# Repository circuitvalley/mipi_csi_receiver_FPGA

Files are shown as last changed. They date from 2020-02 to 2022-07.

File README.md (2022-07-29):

# MIPI CSI-2 Receiver on FPGA , USB 3.0 UVC 2Gbps Video Stream Over Cypress FX3 , Legacy!!

This Repo contains hardware, Verilog source and USB3.0 USB video device class (UVC) Controller C source for generic FPGA CSI receiver. No FPGA hardware specific components has been used so can be easily ported to any low cost FPGA. 

Supports Frame Rate from 15 to 1000 FPS , Resolution From 640x80 to Full 8M 3280x2464.<br>
Max data rate ~2Gbps at 1080p 60FPS. <br>
Full control of Frame rate and Resolution over UVC control. Manual Exposure and manual Brightness control for now. Manual exposure is mapped to UVC saturation Control. Test Pattern can also be enabled with mapped gamma control. 

Test Has been done at</br>
3280x2464 15FPS</br>
1920x1080 60FPS</br>
1920x1080 30FPS</br>
1280x720  120FPS</br>
1280x720  60FPS</br>
1280x720  30FPS</br>
640x480   200FPS</br>
640x480   30FPS</br>
640x128   682FPS</br>
640x80    1000FPS</br>

### This is Now Legacy Version! New version available.
I have published an improved version of FPGA ISP implimention, New version support versious Image format with variable Pipleline width and Higher speed also decoulped Output clock to achive higer throughput , here you can find source of new version here. 
https://github.com/circuitvalley/USB_C_Industrial_Camera_FPGA_USB3

MIPI CSI-2 Receiver on Lattice FPGA (c) by Gaurav Singh www.CircuitValley.com
MIPI CSI-2 Receiver on Lattice FPGA is licensed under a
Creative Commons Attribution 3.0 Unported License.
You should have received a copy of the license along with this
work.  If not, see <http://creativecommons.org/licenses/by/3.0/>.

Shield: [][cc-by]

This work is licensed under a [Creative Commons Attribution 4.0 International
License][cc-by].

[][cc-by]

[cc-by]: http://creativecommons.org/licenses/by/4.0/
[cc-by-image]: https://i.creativecommons.org/l/by/4.0/88x31.png
[cc-by-shield]: https://img.shields.io/badge/License-CC%20BY%204.0-lightgrey.svg

## Camera module 

https://www.circuitvalley.com/2020/02/diy-imx219-4-lane-mipi-breakout-board-raspberry-pi-camera-fpga-4-lane-mipi-csi.html

https://www.circuitvalley.com/2020/02/imx219-camera-mipi-csi-receiver-fpga-lattice-raspberry-pi-camera.html

## Project Video
<a href="https://www.youtube.com/watch?v=HxytsTGWODs">
IMX219
</a>

## Sensor Board Video 
<a href="https://www.youtube.com/watch?v=GFmE3KYa5zs">
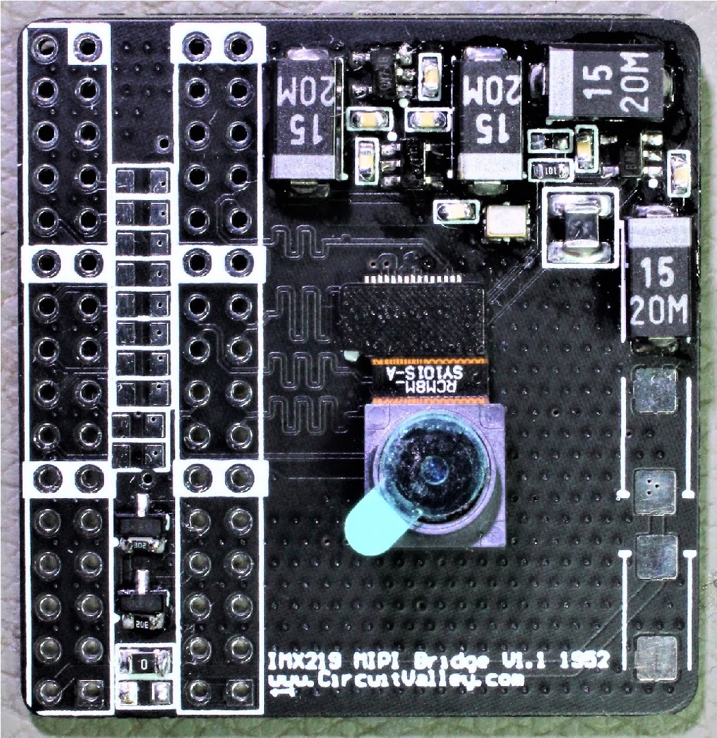
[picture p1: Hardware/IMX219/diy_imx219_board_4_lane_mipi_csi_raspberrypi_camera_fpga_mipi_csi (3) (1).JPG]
IMX219

</a>

## Sensor Image Qaulity Video 

<a href="https://www.youtube.com/watch?v=uRaHXo-Zu90">
IMX219
</a>

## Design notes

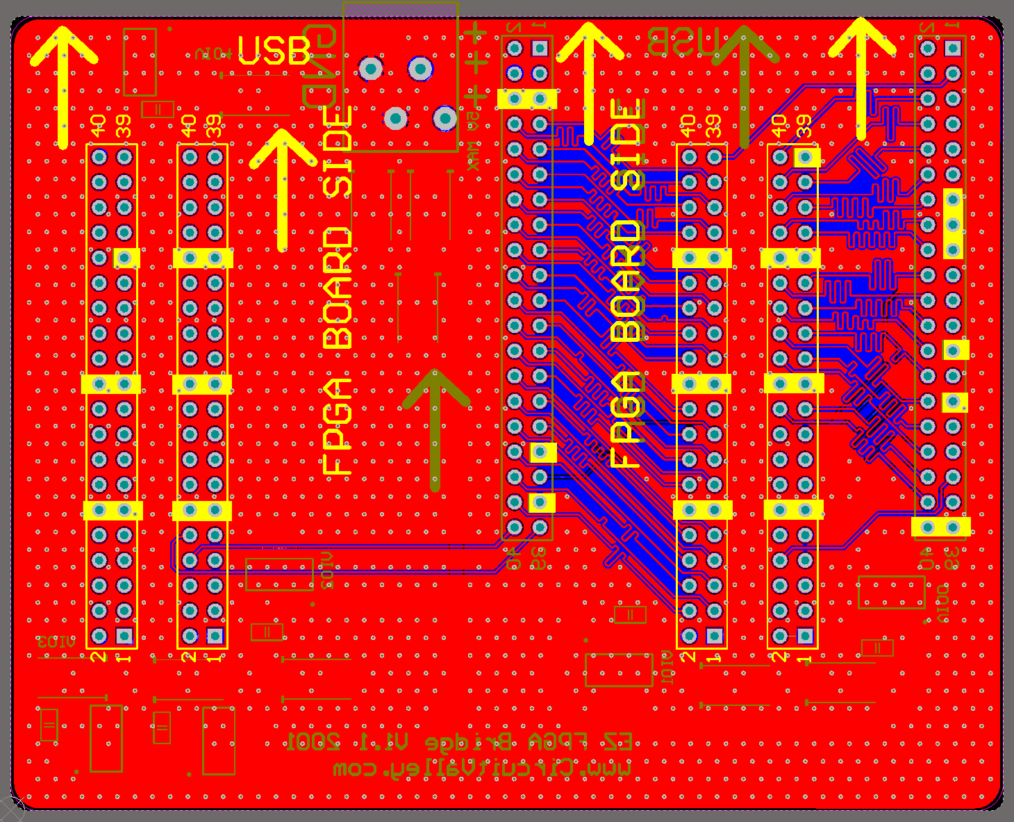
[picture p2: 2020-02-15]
Hardware/Lattice MachXO3 USB3 FX3 Interface Board/Cypress FX3 Lattice MachXO3 FPGA.png

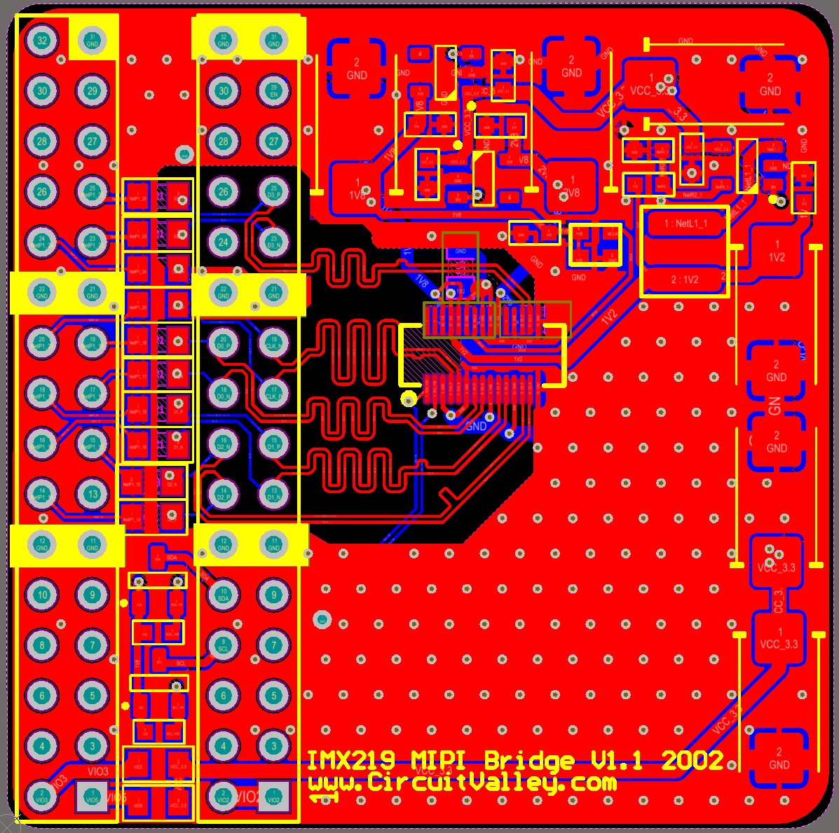
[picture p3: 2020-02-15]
Hardware/IMX219/diy_imx219_board_4_lane_mipi_csi_raspberrypi_camera_fpga_mipi_csi (8).JPG

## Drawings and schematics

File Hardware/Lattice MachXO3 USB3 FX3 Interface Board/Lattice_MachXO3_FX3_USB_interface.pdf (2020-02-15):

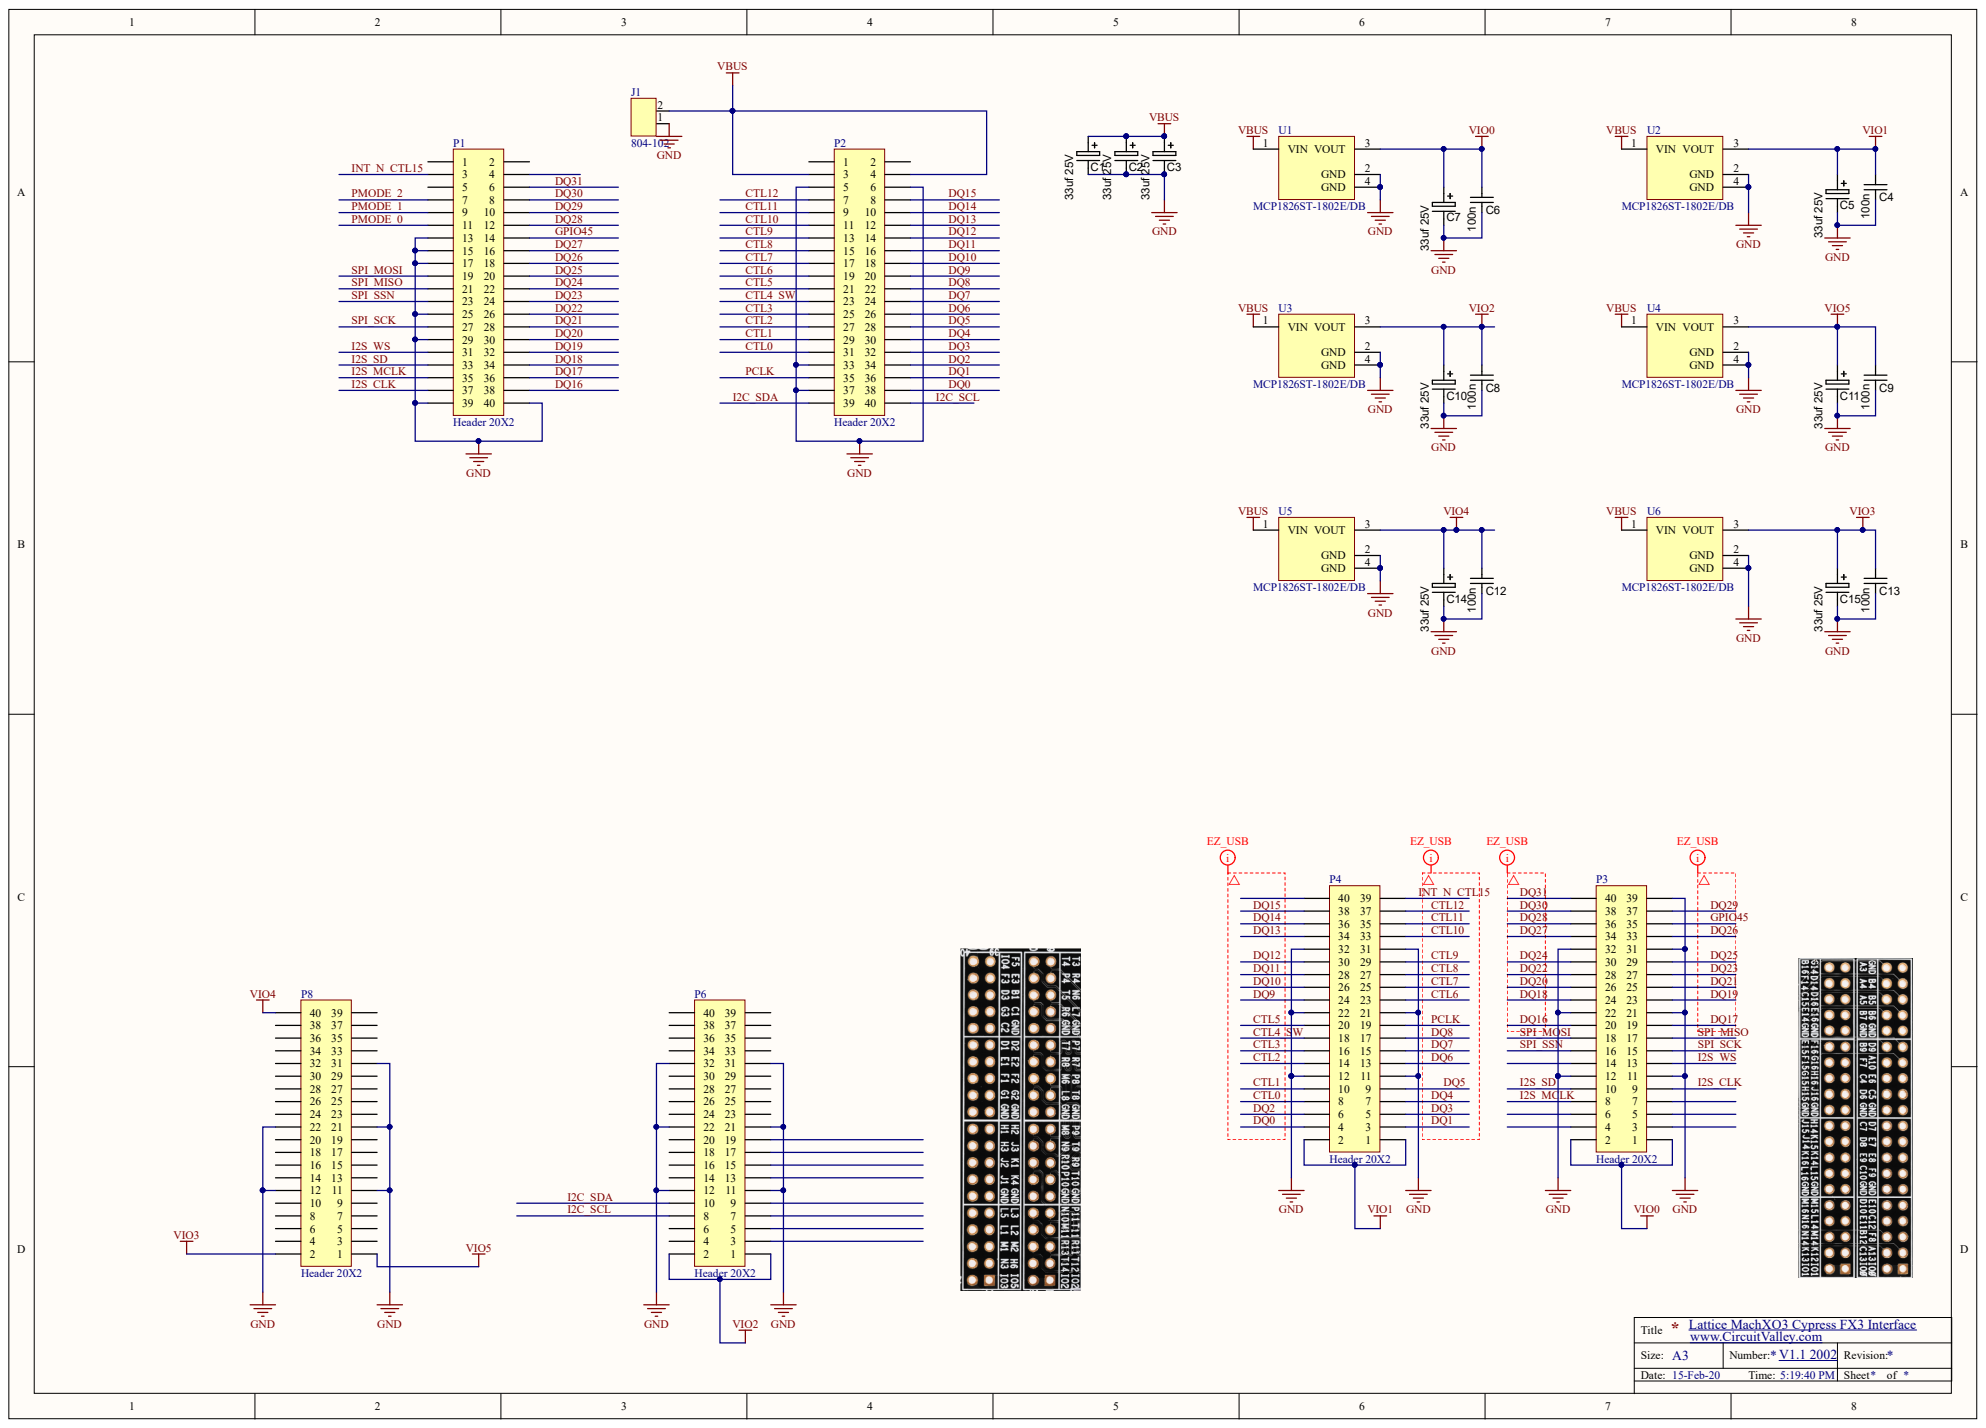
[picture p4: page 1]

Lattice MachXO3 Cypress FX3 Interface www.CircuitValley.com
Title

Size: A3 | Number: * V1.1 2002 | Revision: *

Date: 15-Feb-20 Time: 5:19:40 PM | | Sheet * of *

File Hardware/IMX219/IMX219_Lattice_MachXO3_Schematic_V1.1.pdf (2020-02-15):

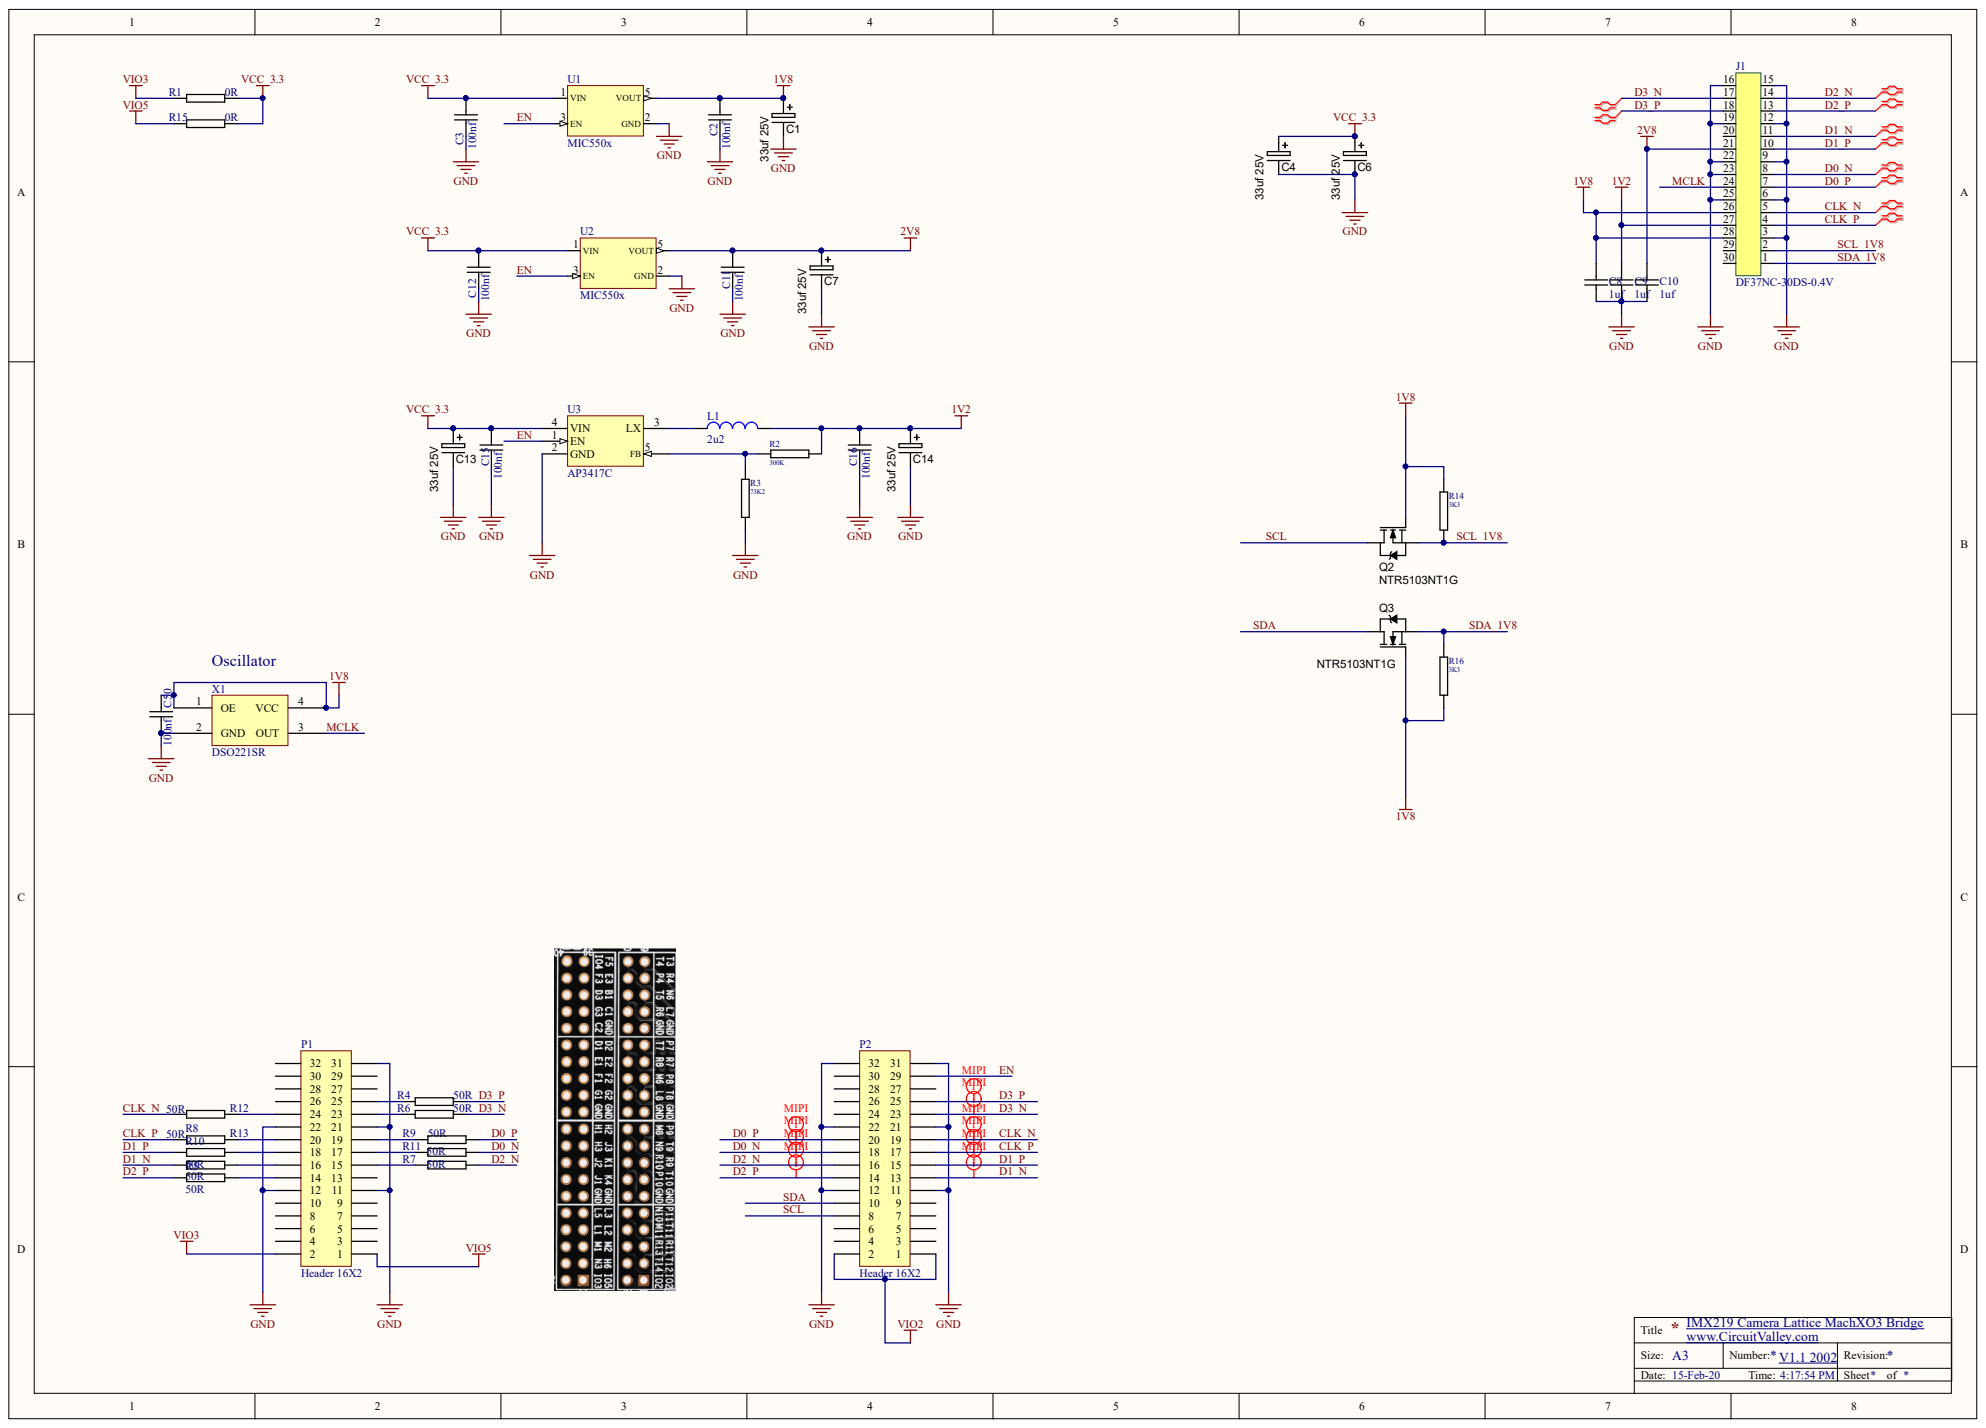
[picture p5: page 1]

22
23 | | 8 7 6
24 25

26 | | 5 4 3
27
28

Size: A3 | Number: * V1.1 2002 | Revision: *

Date: 15-Feb-20 Time: 4:17:54 PM | | Sheet * of *

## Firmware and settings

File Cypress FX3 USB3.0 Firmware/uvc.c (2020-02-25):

#include <cyu3system.h>
#include <cyu3os.h>
#include <cyu3dma.h>
#include <cyu3error.h>
#include <cyu3usb.h>
#include <cyu3uart.h>
#include <cyu3gpif.h>
#include <cyu3i2c.h>
#include <cyu3gpio.h>
#include <cyu3pib.h>
#include <cyu3utils.h>
#include <cyu3socket.h>

#include "uvc.h"
#include "sensor_imx219.h"
#include "camera_ptzcontrol.h"
#include "cyfxgpif2config.h"
#include "uvc_settings.h"
/*************************************************************************************************
                                         Global Variables
 *************************************************************************************************/
static CyU3PThread   uvcAppThread;                      /* UVC video streaming thread. */
static CyU3PThread   uvcAppEP0Thread;                   /* UVC control request handling thread. */
static CyU3PEvent    glFxUVCEvent;                      /* Event group used to signal threads. */
CyU3PDmaMultiChannel glChHandleUVCStream;               /* DMA multi-channel handle. */

/* Current UVC control request fields. See USB specification for definition. */
uint8_t  bmReqType, bRequest;                           /* bmReqType and bRequest fields. */
uint16_t wValue, wIndex, wLength;                       /* wValue, wIndex and wLength fields. */

CyU3PUSBSpeed_t usbSpeed = CY_U3P_NOT_CONNECTED;        /* Current USB connection speed. */
CyBool_t        streamingStarted = CyFalse;             /* Whether USB host has started streaming data */
CyBool_t        glIsApplnActive  = CyFalse;             /* When CLEAR_FEATURE (stop streaming) request is sent this variable is reset and set when start
                                                           streaming request is sent by Host. This is used during commit buffer failure event. */
static CyBool_t glIsConfigured = CyFalse;               /* Whether Application is in configured state or not */

/* Mac OS does not send EP Clear feature when the app is closed. It just stops issuing IN tokens. So buffer commit failures
 * can be counted and if it reaches beyond a limit, streaming can be stopped. Buffer commit failure code can be cleared
 * on DMA Consumer event so that the limit is not reached under streaming conditions.  */
static uint8_t glCommitBufferFailureCount = 0;

/*Variable to track whether the reason for DMA Reset is Frame Timer overflow or Commit Buffer Failure*/
static uint8_t glDmaResetFlag = CY_FX_UVC_DMA_RESET_EVENT_NOT_ACTIVE;

static uint8_t glUvcVcErrorCode = CY_FX_UVC_VC_ERROR_CODE_NO_ERROR;

#ifdef FRAME_TIMER_ENABLE

/* Maximum frame transfer time in milli-seconds. The value is updated for every resolution and frame rate.
 * Note: The value should always be greater than the frame blanking period */
uint16_t glFrameTimerPeriod = CY_FX_UVC_FRAME_TIMER_VAL_200MS;

/* Timer used to track frame transfer time. */
static CyU3PTimer UvcTimer;

/* Frame timer overflow call back function */
static void CyFxUvcAppProgressTimer(uint32_t arg)
{
    if(glDmaResetFlag == CY_FX_UVC_DMA_RESET_EVENT_NOT_ACTIVE)
    {
        glDmaResetFlag = CY_FX_UVC_DMA_RESET_FRAME_TIMER_OVERFLOW;
        CyU3PEventSet(&glFxUVCEvent, CY_FX_UVC_DMA_RESET_EVENT, CYU3P_EVENT_OR);
    }
}
#endif

#ifdef BACKFLOW_DETECT
uint8_t back_flow_detected = 0;                         /* Whether buffer overflow error is detected. */
#endif

#ifdef USB_DEBUG_INTERFACE
CyU3PDmaChannel  glDebugCmdChannel;                     /* Channel to receive debug commands on. */
CyU3PDmaChannel  glDebugRspChannel;                     /* Channel to send debug responses on. */
uint8_t         *glDebugRspBuffer;                      /* Buffer used to send debug responses. */
#endif

/* UVC Probe Control Settings for a USB 3.0 connection. */
uint8_t glProbeCtrl[CY_FX_UVC_MAX_PROBE_SETTING] = {
    0x00, 0x00,                 /* bmHint : no hit */
    0x01,                       /* Use 1st Video format index */
    0x01,                       /* Use 1st Video frame index */
    DBVAL(INTERVAL_30),     /* Desired frame interval in the unit of 100ns: 30 fps */
    0x00, 0x00,                 /* Key frame rate in key frame/video frame units: only applicable
                                   to video streaming with adjustable compression parameters */
    0x00, 0x00,                 /* PFrame rate in PFrame / key frame units: only applicable to
                                   video streaming with adjustable compression parameters */
    0x00, 0x00,                 /* Compression quality control: only applicable to video streaming
                                   with adjustable compression parameters */
    0x00, 0x00,                 /* Window size for average bit rate: only applicable to video
                                   streaming with adjustable compression parameters */
    0x00, 0x00,                 /* Internal video streaming i/f latency in ms */
    DBVAL(MAX_FRAME_SIZE),     /* Max video frame size in bytes */
    0x00, 0x80, 0x00, 0x00,      /* No. of bytes device can rx in single payload = 32 KB */

#ifndef FX3_UVC_1_0_SUPPORT
    /* UVC 1.1 Probe Control has additional fields from UVC 1.0 */
    0x00, 0x60, 0xE3, 0x16,             /* Device Clock */
    0x00,                               /* Framing Information - Ignored for uncompressed format*/
    0x00,                               /* Preferred payload format version */
    0x00,                               /* Minimum payload format version */
    0x00                                /* Maximum payload format version */
#endif
};

typedef struct __attribute__((packed)) uvc_control_s
{
	uint16_t hint;
	uint8_t format_index;
	uint8_t frame_index;
	uint32_t frame_interval;
	uint16_t key_frame_rate;
	uint16_t PFrame_rate;
	uint16_t comp_quality;
	uint16_t comp_win_size;
	uint16_t delay;
	uint32_t max_video_frame_size;
	uint32_t max_payload_transfer_size;
#ifndef FX3_UVC_1_0_SUPPORT
	uint32_t device_clock;
	uint8_t	frame_info;
	uint8_t prefered_version;
	uint8_t min_version;
	uint8_t max_version;
#endif
	uint8_t align_16[14];
}uvc_control_t;

/* UVC Probe Control Setting for a USB 2.0 connection. */
uint8_t glProbeCtrl20[CY_FX_UVC_MAX_PROBE_SETTING] = {
    0x00, 0x00,                 /* bmHint : no hit */
    0x01,                       /* Use 1st Video format index */
    0x01,                       /* Use 1st Video frame index */
    DBVAL(INTERVAL_30),    /* Desired frame interval in the unit of 100ns: 15 fps */
    0x00, 0x00,                 /* Key frame rate in key frame/video frame units: only applicable
                                   to video streaming with adjustable compression parameters */
    0x00, 0x00,                 /* PFrame rate in PFrame / key frame units: only applicable to
                                   video streaming with adjustable compression parameters */
    0x00, 0x00,                 /* Compression quality control: only applicable to video streaming
                                   with adjustable compression parameters */
    0x00, 0x00,                 /* Window size for average bit rate: only applicable to video
                                   streaming with adjustable compression parameters */
    0x00, 0x00,                 /* Internal video streaming i/f latency in ms */
    DBVAL(MAX_FRAME_SIZE),     /* Max video frame size in bytes */
    0x00, 0x80, 0x00, 0x00,      /* No. of bytes device can rx in single payload = 32 KB */

#ifndef FX3_UVC_1_0_SUPPORT
    /* UVC 1.1 Probe Control has additional fields from UVC 1.0 */
    0x00, 0x60, 0xE3, 0x16,             /* Device Clock */
    0x00,                               /* Framing Information - Ignored for uncompressed format*/
    0x00,                               /* Preferred payload format version */
    0x00,                               /* Minimum payload format version */
    0x00                                /* Maximum payload format version */
#endif
};

/* Video Probe Commit Control. This array is filled out when the host sends down the SET_CUR request. */
static uint8_t glCommitCtrl[CY_FX_UVC_MAX_PROBE_SETTING_ALIGNED];

/* Scratch buffer used for handling UVC class requests with a data phase. */
static uint8_t glEp0Buffer[32];

/* UVC Header to be prefixed at the top of each 16 KB video data buffer. */
uint8_t volatile glUVCHeader[CY_FX_UVC_MAX_HEADER] =
{
    0x0C,                               /* Header Length */
    0x8C,                               /* Bit field header field */
    0x00, 0x00, 0x00, 0x00,             /* Presentation time stamp field */
    0x00, 0x00, 0x00, 0x00, 0x00, 0x00  /* Source clock reference field */
};

#ifdef UVC_EXTENSION_UNIT

/* Format is: Version 1.0 (Major.Minor) Build date: 9/10/17 (MM/DD/YY) */
static uint8_t glFxUvcFirmwareVersion[5] = {
    1,       /* Major version */
    0,       /* Minor version */
    9,       /* Build month */
    22,      /* Build day */
    17       /* Build Year */
};
#endif

#ifdef DEBUG_PRINT_FRAME_COUNT
volatile static uint32_t glFrameCount = 0;              /* Number of video frames transferred so far. */
volatile static uint32_t glDmaDone = 1;                 /* Number of buffers transferred in the current frame. */
#endif
volatile static uint32_t gTotal_bytes = 0;

/* Add the UVC packet header to the top of the specified DMA buffer. */
void
CyFxUVCAddHeader (
        uint8_t *buffer_p,              /* Buffer pointer */
        uint8_t frameInd                /* EOF or normal frame indication */
        )
{
    /* Copy header to buffer */
    CyU3PMemCopy (buffer_p, (uint8_t *)glUVCHeader, CY_FX_UVC_MAX_HEADER);

    /* The EOF flag needs to be set if this is the last packet for this video frame. */
    if (frameInd & CY_FX_UVC_HEADER_EOF)
    {
        buffer_p[1] |= CY_FX_UVC_HEADER_EOF;
        glUVCHeader[1] ^= CY_FX_UVC_HEADER_FRAME_ID;
    }
}


/* Application Error Handler */
void
CyFxAppErrorHandler (
        CyU3PReturnStatus_t apiRetStatus    /* API return status */
        )
{
    /* This function is hit when we have hit a critical application error. This is not
       expected to happen, and the current implementation of this function does nothing
       except stay in a loop printing error messages through the UART port.

       This function can be modified to take additional error handling actions such
       as cycling the USB connection or performing a warm reset.
     */
    for (;;)
    {
        CyU3PDebugPrint (4, "Error handler...\r\n");
        CyU3PThreadSleep (1000);
    }
}

/* This function performs the operations for a Video Streaming Abort.
   This is called every time there is a USB reset, suspend or disconnect event.
 */
static void
CyFxUVCApplnAbortHandler (
        void)
{
    /* Set Video Stream Abort Event */
    CyU3PEventSet (&glFxUVCEvent, CY_FX_UVC_STREAM_ABORT_EVENT, CYU3P_EVENT_OR);
}

/* This is the Callback function to handle the USB Events */
static void
CyFxUVCApplnUSBEventCB (
        CyU3PUsbEventType_t evtype,  /* Event type */
        uint16_t             evdata  /* Event data */
        )
{
    switch (evtype)
    {
        case CY_U3P_USB_EVENT_SUSPEND:
            CyU3PDebugPrint (4, "UsbEventCB: SUSPEND encountered...\r\n");
            /* Set USB suspend Event */
            CyU3PEventSet (&glFxUVCEvent, CY_FX_USB_SUSPEND_EVENT_HANDLER, CYU3P_EVENT_OR);
            break;

        case CY_U3P_USB_EVENT_EP_UNDERRUN:
            CyU3PDebugPrint (4, "UsbEventCB: CY_U3P_USB_EVENT_EP_UNDERRUN encountered...\r\n");
            break;

        /* Intentional Fall-through all cases */
        case CY_U3P_USB_EVENT_SETCONF:
            if (CyU3PUsbGetSpeed() == CY_U3P_SUPER_SPEED)
            {
                CyU3PDebugPrint(4, "UsbEventCB: Detected SS USB Connection\r\n");
            }
            else if (CyU3PUsbGetSpeed() == CY_U3P_HIGH_SPEED)
            {
                CyU3PDebugPrint(4, "UsbEventCB: Detected HS USB Connection\r\n");
            }
        case CY_U3P_USB_EVENT_RESET:
        case CY_U3P_USB_EVENT_DISCONNECT:
        case CY_U3P_USB_EVENT_CONNECT:
            if (evtype == CY_U3P_USB_EVENT_SETCONF)
              glIsConfigured = CyTrue;
            else
              glIsConfigured = CyFalse;

            /* Stop the video streamer application and enable LPM. */
            CyU3PUsbLPMEnable();
            if (glIsApplnActive)
            {
              CyU3PDebugPrint(4, "UsbEventCB: Call App Stop\r\n");
              CyFxUVCApplnAbortHandler();
            }
            break;

        default:
            break;
    }
}

/* Callback to handle the USB Setup Requests and UVC Class events */
static CyBool_t
CyFxUVCApplnUSBSetupCB (
        uint32_t setupdat0, /* SETUP Data 0 */
        uint32_t setupdat1  /* SETUP Data 1 */
        )
{
    CyBool_t uvcHandleReq = CyFalse;
    uint32_t status;

    /* Obtain Request Type and Request */
    bmReqType = (uint8_t)(setupdat0 & CY_FX_USB_SETUP_REQ_TYPE_MASK);
    bRequest  = (uint8_t)((setupdat0 & CY_FX_USB_SETUP_REQ_MASK) >> 8);
    wValue    = (uint16_t)((setupdat0 & CY_FX_USB_SETUP_VALUE_MASK) >> 16);
    wIndex    = (uint16_t)(setupdat1 & CY_FX_USB_SETUP_INDEX_MASK);
    wLength   = (uint16_t)((setupdat1 & CY_FX_USB_SETUP_LENGTH_MASK) >> 16);

    /* Check for UVC Class Requests */
    switch (bmReqType)
    {
        case CY_FX_USB_UVC_GET_REQ_TYPE:
        case CY_FX_USB_UVC_SET_REQ_TYPE:
            /* UVC Specific requests are handled in the EP0 thread. */
            switch (wIndex & 0xFF)
            {
                case CY_FX_UVC_CONTROL_INTERFACE:
                    {
                        uvcHandleReq = CyTrue;
                        status = CyU3PEventSet (&glFxUVCEvent, CY_FX_UVC_VIDEO_CONTROL_REQUEST_EVENT, CYU3P_EVENT_OR);
                        if (status != CY_U3P_SUCCESS)
                        {
                            CyU3PDebugPrint (4, "Set CY_FX_UVC_VIDEO_CONTROL_REQUEST_EVENT Failed %x\r\n", status);
                            CyU3PUsbStall (0, CyTrue, CyFalse);
                        }
                    }
                    break;

                case CY_FX_UVC_STREAM_INTERFACE:
                    {
                        uvcHandleReq = CyTrue;
                        status = CyU3PEventSet (&glFxUVCEvent, CY_FX_UVC_VIDEO_STREAM_REQUEST_EVENT, CYU3P_EVENT_OR);
                        if (status != CY_U3P_SUCCESS)
                        {
                            /* Error handling */
                            CyU3PDebugPrint (4, "Set CY_FX_UVC_VIDEO_STREAM_REQUEST_EVENT Failed %x\r\n", status);
                            CyU3PUsbStall (0, CyTrue, CyFalse);
                        }
                    }
                    break;

                default:
                    break;
            }
            break;

        case CY_FX_USB_SET_INTF_REQ_TYPE:
            if (bRequest == CY_FX_USB_SET_INTERFACE_REQ)
            {
                /* Some hosts send Set Interface Alternate Setting 0 command while stopping the video
                 * stream. The application uses this event to stop streaming. */
                if ((wIndex == CY_FX_UVC_STREAM_INTERFACE) && (wValue == 0))
                {
                    /* Stop GPIF state machine to stop data transfers through FX3 */
                    CyU3PDebugPrint (4, "Alternate setting 0..\r\n");

                    /* Clear the stall condition and sequence numbers. */
                    CyU3PUsbStall (CY_FX_EP_BULK_VIDEO, CyFalse, CyTrue);
                    CyFxUVCApplnAbortHandler ();

                    uvcHandleReq = CyTrue;
                    /* Complete Control request handshake */
                    CyU3PUsbAckSetup ();
                }
            }
            else if ((bRequest == CY_U3P_USB_SC_SET_FEATURE) || (bRequest == CY_U3P_USB_SC_CLEAR_FEATURE))
            {
                CyU3PDebugPrint(4, "USBSetupCB:In SET_FTR %d::%d\r\n", glIsApplnActive, glIsConfigured);
                if (glIsConfigured)
                {
                    uvcHandleReq = CyTrue;
                    CyU3PUsbAckSetup ();
                }
            }

            break;

        case CY_U3P_USB_TARGET_ENDPT:
            if (bRequest == CY_U3P_USB_SC_CLEAR_FEATURE)
            {
                if (wIndex == CY_FX_EP_BULK_VIDEO)
                {
                    /* Windows OS sends Clear Feature Request after it stops streaming,
                     * however MAC OS sends clear feature request right after it sends a
                     * Commit -> SET_CUR request. Hence, stop the video streaming and clear
                     * the stall condition and sequence numbers */
                    CyU3PDebugPrint (4, "Clear feature request detected...\r\n");

                    /* Clear the stall condition and sequence numbers. */
                    CyU3PUsbStall (CY_FX_EP_BULK_VIDEO, CyFalse, CyTrue);
                    CyFxUVCApplnAbortHandler();

                    uvcHandleReq = CyTrue;
                    /* Complete Control request handshake */
                    CyU3PUsbAckSetup ();
                }
            }
            break;

        default:
            break;
    }

    /* Return status of request handling to the USB driver */
    return uvcHandleReq;
}

/* DMA callback providing notification when data buffers are received from the sensor and when they have
 * been drained by the USB host.
 *
 * The UVC headers are attached to the data, and forwarded to the USB host in this callback function.
 */
void
CyFxUvcApplnDmaCallback (
        CyU3PDmaMultiChannel *chHandle,
        CyU3PDmaCbType_t      type,
        CyU3PDmaCBInput_t    *input
        )
{
    CyU3PDmaBuffer_t    dmaBuffer;
    CyU3PReturnStatus_t status = CY_U3P_SUCCESS;





    if (type == CY_U3P_DMA_CB_PROD_EVENT)
    {
        /* This is a produce event notification to the CPU. This notification is received upon reception of
         * every buffer. The buffer will not be sent out unless it is explicitly committed. The call shall fail
         * if there is a bus reset / usb disconnect or if there is any application error.
         */
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
int
main (
        void)
{
    CyU3PReturnStatus_t apiRetStatus;
    CyU3PIoMatrixConfig_t io_cfg;

    CyU3PSysClockConfig_t clk_cfg;
    /* Initialize the device */
    clk_cfg.setSysClk400  = CyTrue;
    clk_cfg.cpuClkDiv     = 2;
    clk_cfg.dmaClkDiv     = 2;
    clk_cfg.mmioClkDiv    = 2;
    clk_cfg.useStandbyClk = CyFalse;
    clk_cfg.clkSrc        = CY_U3P_SYS_CLK;
    apiRetStatus = CyU3PDeviceInit (&clk_cfg);
    if (apiRetStatus != CY_U3P_SUCCESS)
    {
        goto handle_fatal_error;
    }

    /* Turn on instruction cache to improve firmware performance. Use Release build to improve it further */
    apiRetStatus = CyU3PDeviceCacheControl (CyTrue, CyFalse, CyFalse);

    /* Configure the IO matrix for the device. */
    io_cfg.isDQ32Bit        = CyTrue;
    io_cfg.s0Mode       	= CyFalse;
    io_cfg.s1Mode	        = CyFalse;
    io_cfg.lppMode          = CY_U3P_IO_MATRIX_LPP_DEFAULT;
    io_cfg.gpioSimpleEn[0]  = 0;
    io_cfg.gpioSimpleEn[1]  = 0;
    io_cfg.gpioComplexEn[0] = 0;
    io_cfg.gpioComplexEn[1] = 0;
    io_cfg.useUart          = CyTrue;   /* Uart is enabled for logging. */
    io_cfg.useI2C           = CyTrue;   /* I2C is used for the sensor interface. */
    io_cfg.useI2S           = CyFalse;
    io_cfg.useSpi           = CyFalse;

    apiRetStatus = CyU3PDeviceConfigureIOMatrix (&io_cfg);
    if (apiRetStatus != CY_U3P_SUCCESS)
    {
        goto handle_fatal_error;
    }

    /* This is a non returnable call for initializing the RTOS kernel */
    CyU3PKernelEntry ();

    /* Dummy return to make the compiler happy */
    return 0;

handle_fatal_error:
    /* Cannot recover from this error. */
    while (1);
}

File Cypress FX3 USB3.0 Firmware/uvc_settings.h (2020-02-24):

/*
 * uvc_settings.h
 *
 *  Created on: Jan 25, 2020
 *      Author: gaurav
 */

#ifndef UVC_SETTINGS_H_
#define UVC_SETTINGS_H_


#define WBVAL(x) (x & 0xFF),((x >> 8) & 0xFF)
#define DBVAL(x) (x & 0xFF),((x >> 8) & 0xFF),((x >> 16) & 0xFF),((x >> 24) & 0xFF)

#define UVC_WIDTH                                     (unsigned int)3280
#define UVC_HEIGHT                                    (unsigned int)2462

#define CAM_FPS_1000                                  1000
#define CAM_FPS_682                                   682
#define CAM_FPS_200                                   200
#define CAM_FPS_120                                   120
#define CAM_FPS_60                                    60
#define CAM_FPS_30                                    30
#define CAM_FPS_15                                    15

#define INTERVAL_1000								(unsigned long)(10000000/CAM_FPS_1000)
#define INTERVAL_682								(unsigned long)(10000000/CAM_FPS_682)
#define INTERVAL_200								(unsigned long)(10000000/CAM_FPS_200)
#define INTERVAL_120								(unsigned long)(10000000/CAM_FPS_120)
#define INTERVAL_60									(unsigned long)(10000000/CAM_FPS_60)
#define INTERVAL_30									(unsigned long)(10000000/CAM_FPS_30)
#define INTERVAL_15									(unsigned long)(10000000/CAM_FPS_15)

//640x480 supports 30 and 200FPS
#define UVC_WIDTH_640								(unsigned int)640
#define UVC_HEIGHT_126								(unsigned int)126
#define MIN_BIT_RATE_640x126						(unsigned long)(UVC_WIDTH_640*UVC_HEIGHT_126*16*CAM_FPS_682) //YUY2 4byte per 2 pixel
#define MAX_BIT_RATE_640x126						(unsigned long)(UVC_WIDTH_640*UVC_HEIGHT_126*16*CAM_FPS_682)
#define MAX_FRAME_SIZE_640x126						(unsigned long)(UVC_WIDTH_640*UVC_HEIGHT_126*2)//YUY2 4byte per 2 pixel

#define UVC_WIDTH_640								(unsigned int)640
#define UVC_HEIGHT_78								(unsigned int)78
#define MIN_BIT_RATE_640x78							(unsigned long)(UVC_WIDTH_640*UVC_HEIGHT_78*16*CAM_FPS_1000) //YUY2 4byte per 2 pixel
#define MAX_BIT_RATE_640x78							(unsigned long)(UVC_WIDTH_640*UVC_HEIGHT_78*16*CAM_FPS_1000)
#define MAX_FRAME_SIZE_640x78						(unsigned long)(UVC_WIDTH_640*UVC_HEIGHT_78*2)//YUY2 4byte per 2 pixel

#define UVC_WIDTH_640								(unsigned int)640
#define UVC_HEIGHT_480								(unsigned int)480
#define MIN_BIT_RATE_640x480						(unsigned long)(UVC_WIDTH_640*UVC_HEIGHT_480*16*CAM_FPS_30) //YUY2 4byte per 2 pixel
#define MAX_BIT_RATE_640x480						(unsigned long)(UVC_WIDTH_640*UVC_HEIGHT_480*16*CAM_FPS_200)
#define MAX_FRAME_SIZE_640x480						(unsigned long)(UVC_WIDTH_640*UVC_HEIGHT_480*2)//YUY2 4byte per 2 pixel

#define UVC_WIDTH_1280								(unsigned int)1280
#define UVC_HEIGHT_720								(unsigned int)720
#define MIN_BIT_RATE_1280x720						(unsigned long)(UVC_WIDTH_1280*UVC_HEIGHT_720*16*CAM_FPS_30)
#define MAX_BIT_RATE_1280x720						(unsigned long)(UVC_WIDTH_1280*UVC_HEIGHT_720*16*CAM_FPS_120)
#define MAX_FRAME_SIZE_1280x720						(unsigned long)(UVC_WIDTH_1280*UVC_HEIGHT_720*2)

#define UVC_WIDTH_1920								(unsigned int)1920
#define UVC_HEIGHT_1080								(unsigned int)1080
#define MIN_BIT_RATE_1920x1080						(unsigned long)(UVC_WIDTH_1920*UVC_HEIGHT_1080*16*CAM_FPS_30)
#define MAX_BIT_RATE_1920x1080						(unsigned long)(UVC_WIDTH_1920*UVC_HEIGHT_1080*16*CAM_FPS_60)
#define MAX_FRAME_SIZE_1920x1080					(unsigned long)(UVC_WIDTH_1920*UVC_HEIGHT_1080*2)

#define UVC_WIDTH_3280								(unsigned int)3280
#define UVC_HEIGHT_2462								(unsigned int)2462
#define MIN_BIT_RATE_3280x2462						(unsigned long)(UVC_WIDTH_3280*UVC_HEIGHT_2462*16*CAM_FPS_15)
#define MAX_BIT_RATE_3280x2462						(unsigned long)(UVC_WIDTH_3280*UVC_HEIGHT_2462*16*CAM_FPS_15)
#define MAX_FRAME_SIZE_3280x2462					(unsigned long)(UVC_WIDTH_3280*UVC_HEIGHT_2462*2)


#define MAX_FRAME_SIZE                              (unsigned long)(UVC_WIDTH_3280*UVC_HEIGHT_2462*2)//yuy2


typedef enum
{
	FRAME_640x480 = 1,
	FRAME_1280x720,
	FRAME_1920x1080,
	FRAME_3280x2462,
	FRMAE_640x128,
	FRMAE_640x80,
}frame_t;

#endif /* UVC_SETTINGS_H_ */

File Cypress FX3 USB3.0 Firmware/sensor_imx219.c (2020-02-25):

#include <cyu3system.h>
#include <cyu3os.h>
#include <cyu3dma.h>
#include <cyu3error.h>
#include <cyu3uart.h>
#include <cyu3i2c.h>
#include <cyu3types.h>
#include <cyu3gpio.h>
#include <cyu3utils.h>
#include "sensor_imx219.h"
#include "uvc_settings.h"

imgsensor_mode_t *selected_img_mode;


static const imx219_reg_t mode_default[]={	//default register settings, Resolution and FPS specific settings will be over written
		 {REG_MODE_SEL,			0x00},
		 {0x30EB,				0x05},	//access sequence
		 {0x30EB,				0x0C},
		 {0x300A,				0xFF},
		 {0x300B,				0xFF},
		 {0x30EB,				0x05},
		 {0x30EB,				0x09},
		 {REG_CSI_LANE,			0x03},	//3-> 4Lane 1-> 2Lane
		 {REG_DPHY_CTRL,		0x00},	//DPHY timing 0-> auot 1-> manual
		 {REG_EXCK_FREQ_MSB,	0x18},	//external oscillator frequncy 0x18 -> 24Mhz
		 {REG_EXCK_FREQ_LSB,	0x00},
		 {REG_FRAME_LEN_MSB,	0x06},	//frame length , Raspberry pi sends this commands continously when recording video @60fps ,writes come at interval of 32ms , Data 355 for resolution 1280x720 command 162 also comes along with data 0DE7 also 15A with data 0200
		 {REG_FRAME_LEN_LSB,	0xE3},
		 {REG_LINE_LEN_MSB,		0x0d},	//does not directly affect how many bits on wire in one line does affect how many clock between lines
		 {REG_LINE_LEN_LSB,		0x78},	//appears to be having step in value, not every LSb change will reflect on fps
		 {REG_X_ADD_STA_MSB,	0x02},	//x start
		 {REG_X_ADD_STA_LSB,	0xA8},
		 {REG_X_ADD_END_MSB,	0x0A},	//x end
		 {REG_X_ADD_END_LSB,	0x27},
		 {REG_Y_ADD_STA_MSB,	0x02},	//y start
		 {REG_Y_ADD_STA_LSB,	0xB4},
		 {REG_Y_ADD_END_MSB,	0x06},	//y end
		 {REG_Y_ADD_END_LSB,	0xEB},
		 {REG_X_OUT_SIZE_MSB,	0x07},	//resolution 1280 -> 5 00 , 1920 -> 780 , 2048 -> 0x8 0x00
		 {REG_X_OUT_SIZE_LSB,	0x80},
		 {REG_Y_OUT_SIZE_MSB,	0x04},	// 720 -> 0x02D0 | 1080 -> 0x438  | this setting changes how many line over wire does not affect frame rate
		 {REG_Y_OUT_SIZE_LSB,	0x38},
		 {REG_X_ODD_INC,		0x01},	//increment
		 {REG_Y_ODD_INC,		0x01},	//increment
		 {REG_BINNING_H,		0x00},	//binning H 0 off 1 x2 2 x4 3 x2 analog
		 {REG_BINNING_V,		0x00},	//binning H 0 off 1 x2 2 x4 3 x2 analog
		 {REG_CSI_FORMAT_C,		0x0A},	//CSI Data format A-> 10bit
		 {REG_CSI_FORMAT_D,		0x0A},	//CSI Data format
		 {REG_VTPXCK_DIV,		0x05},	//vtpxclkd_div	5 301
		 {REG_VTSYCK_DIV,		0x01},	//vtsclk _div  1	303
		 {REG_PREPLLCK_VT_DIV,	0x03},	//external oscillator /3
		 {REG_PREPLLCK_OP_DIV,	0x03},	//external oscillator /3
		 {REG_PLL_VT_MPY_MSB,	0x00},	//PLL_VT multiplizer
		 {REG_PLL_VT_MPY_LSB,	0x52},	//Changes Frame rate with , integration register 0x15a
		 {REG_OPPXCK_DIV,		0x0A},	//oppxck_div
		 {REG_OPSYCK_DIV,		0x01},	//opsysck_div
		 {REG_PLL_OP_MPY_MSB,	0x00},	//PLL_OP
		 {REG_PLL_OP_MPY_LSB,	0x32}, 	// 8Mhz x 0x57 ->696Mhz -> 348Mhz |  0x32 -> 200Mhz | 0x40 -> 256Mhz
		 {0x455E,				0x00},	//magic?
		 {0x471E,				0x4B},
		 {0x4767,				0x0F},
		 {0x4750,				0x14},
		 {0x4540,				0x00},
		 {0x47B4,				0x14},
		 {0x4713,				0x30},
		 {0x478B,				0x10},
		 {0x478F,				0x10},
		 {0x4793,				0x10},
		 {0x4797,				0x0E},
		 {0x479B,				0x0E},
		 {REG_TEST_PATTERN_MSB, 0x00},	//test pattern
		 {REG_TEST_PATTERN_LSB, 0x00},
		 {REG_TP_X_OFFSET_MSB,  0x00}, //tp offset x 0
		 {REG_TP_X_OFFSET_LSB,  0x00},
		 {REG_TP_Y_OFFSET_MSB,  0x00}, //tp offset y 0
		 {REG_TP_Y_OFFSET_LSB,  0x00},
		 {REG_TP_WIDTH_MSB,   	0x05}, //TP width 1920 ->780 1280->500
		 {REG_TP_WIDTH_LSB,   	0x00},
		 {REG_TP_HEIGHT_MSB,   	0x02}, //TP height 1080 -> 438 720->2D0
		 {REG_TP_HEIGHT_LSB,   	0xD0},
		 {REG_DIG_GAIN_GLOBAL_MSB, 	0x01},
		 {REG_DIG_GAIN_GLOBAL_LSB, 	0x00},
		 {REG_ANA_GAIN_GLOBAL, 		0x80}, //analog gain , raspberry pi constinouly changes this depending on scense
		 {REG_INTEGRATION_TIME_MSB, 0x03},	//integration time , really important for frame rate
		 {REG_INTEGRATION_TIME_LSB, 0x51},
		 {REG_MODE_SEL,			0x01},

};


static image_sensor_config_t sensor_config = {
	.sensor_mode = 0x01,

	.mode_640x480_30 = {
		.pix_clk_mul = 0x53,
		.pix_clk_div = 0x4,
		.integration = 3209 - 4,	//must be < (linelength- 4) to maintain frame rate by framelength or integration time will slow frame rate
		.gain = 0x70,
		.linelength = 3448, 	//Warning! This value need to be either 0xD78 or 0xDE7 regardless of frame size and FPS, other values will result undefined and ununderstanable issues in image
		.framelength = 3209,
		.startx = 1000,
		.starty = 750,
		.endx = 2280,
		.endy = 1715,		//this has to odd or bayer oder will change
		.width = 640,
		.height = 482,	//each frame will have two extra line to compensate for debayer crop
		.binning = 2,
		.test_pattern = 0
	},
	.mode_640x480_200 = {
		.pix_clk_mul = 0x53,
		.pix_clk_div = 0x4,
		.integration = 481 - 4,
		.gain = 0x70,
		.linelength = 3448,
		.framelength = 481,
		.startx = 1000,
		.starty = 750,
		.endx = 2280,
		.endy = 1715,
		.width = 640,
		.height = 482,
		.binning = 2,
		.test_pattern = 0
	},

	.mode_1280x720_30 = {
		.pix_clk_mul = 0x58,
		.pix_clk_div = 0x4,
		.integration = 3402 - 10,
		.gain = 0x80,
		.linelength = 3448,
		.framelength = 3402,
		.startx = 4,
		.starty = 4,
		.endx = 0xA27,
		.endy = 0x6EB,
		.width = 1280,
		.height = 722,
		.binning = 0,
		.test_pattern = 0
	},
	.mode_1280x720_60 = {
		.pix_clk_mul = 0x58,
		.pix_clk_div = 0x4,
		.integration = 1701 - 4,
		.gain = 0x80,
		.linelength = 0xD78,
		.framelength = 1701,
		.startx = 0x2A8,
		.starty = 0x2B4,
		.endx = 0xA27,
		.endy = 0x6EB,
		.width = 1280,
		.height = 722,
		.binning = 0,
		.test_pattern = 0
	},
	.mode_1280x720_120 = {		//Camera output @120
		.pix_clk_mul = 0x58,
		.pix_clk_div = 0x4,
		.integration = 850 - 4,
		.gain = 0x80,
		.linelength = 0xD78,
		.framelength = 850,
		.startx = 0x2A8,
		.starty = 0x2B4,
		.endx = 0xA27,
		.endy = 0x6EB,
		.width = 1280,
		.height = 722,
		.binning = 0,
		.test_pattern = 0
	},
	.mode_1920x1080_30 = {		//camera output 1920x1080 @30FPS
		.pix_clk_mul = 0x50,
		.pix_clk_div = 0x5,
		.integration = 2474 - 4,
		.gain = 0x80,
		.linelength = 0xD78,
		.framelength = 2474,
		.startx = 0x2A8,
		.starty = 0x2B4,
		.endx = 0xA27,
		.endy = 0x6EB,
		.width = 1920,
		.height = 1082,
		.binning = 0,
		.test_pattern = 0
	},
	.mode_1920x1080_60 = {		//camera output 1920x1080 @60FPS
		.pix_clk_mul = 0x50,
		.pix_clk_div = 0x5,
		.integration = 1237 - 4,
		.gain = 0x80,
		.linelength = 0xD78,
		.framelength = 1237,
		.startx = 0x2A8,
		.starty = 0x2B4,
		.endx = 0xA27,
		.endy = 0x6EB,
		.width = 1920,
		.height = 1082,
		.binning = 0,
		.test_pattern = 0
	},
	.mode_640x128_682 = {	//camera output 640x128 pixel @682 FPS
		.pix_clk_mul = 0x53,
		.pix_clk_div = 0x4,
		.integration = 141 - 4,
		.gain = 200,
		.linelength = 0xD78,
		.framelength = 141,
		.startx = 1320,
		.starty = 990,
		.endx = 2600,
		.endy = 1609,
		.width = 640,
		.height = 128,
		.binning = 2,
		.test_pattern = 0
	},
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

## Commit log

2020-02-15 Added IMX219 Board Files
    [IMX219_Bridge.PcbDoc, IMX219_Bridge.PrjPcb, IMX219_Bridge.SchDoc]
2020-02-15 Added FX3 FPGA Board interface board files
    [EZ_FPGA_BRIDGE_V2.PrjPcb, EZ_FPGA_Bridge.PcbDoc, EZ_FPGA_Bridge.SchDoc]
2020-02-19 WIP Unstable FW, 640x128 @ 680FPS
    [sensor_imx219.c, sensor_imx219.h, uvc_settings.h]
2020-02-22 Pixel Clock rate to 704Mhz , Various parameter for all frame-rates are calculated
2020-02-23 Fixed firmware issues , increased buffer length Tested with 1280x720 120FPS
    [sensor_imx219.c, uvc.c, uvc.h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]
2020-02-23 Supports full frame @15 FPS, also all listed frame rate Tested
2020-02-24 UVC control Support for all frame rates and resolution implemented.
2020-02-25 Total Camera Control over UVC control. Exposure is mapped to Saturation , Test patter is mapped to Gamma
2020-02-25 sample output image
2020-02-25 Renamed sample image

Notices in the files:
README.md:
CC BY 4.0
